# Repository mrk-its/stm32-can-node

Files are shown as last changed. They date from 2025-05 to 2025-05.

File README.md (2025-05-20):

# STM32 CAN Node

# Features

* modern STM32 MCU (U3/U5 series)
* integrated step-down converter (24V -> 3.3V)
* integrated CAN transceiver
* integrated 1-wire master controller (over i2c)
* 2.54 pin headers exposing 15 GPIOs
* separate SWD connector for flashing / debugging
* separate UART connector
* small form factor (40mm x 25mm)

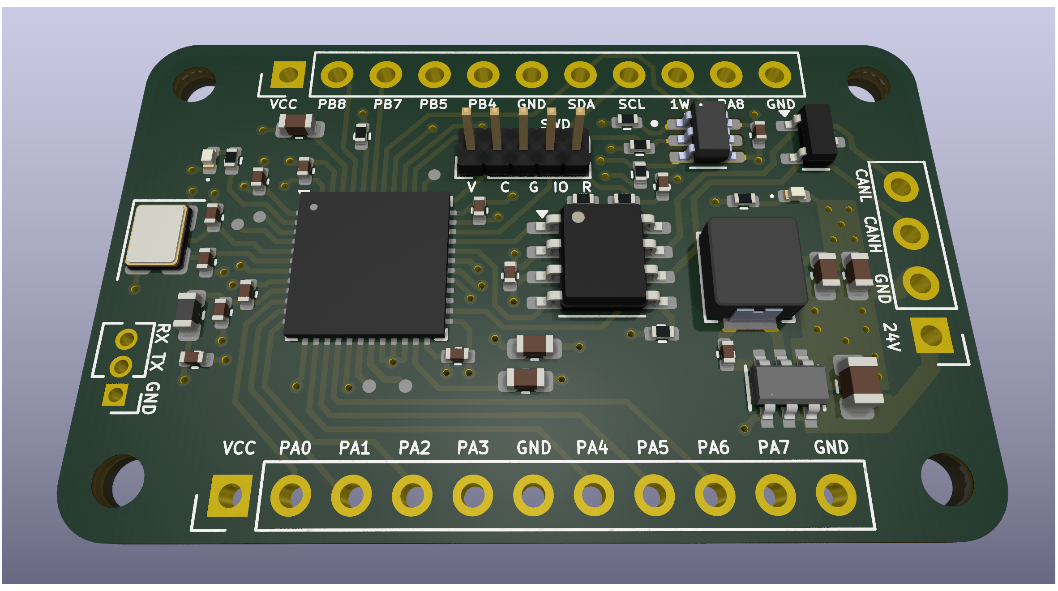
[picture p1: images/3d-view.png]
3d-view


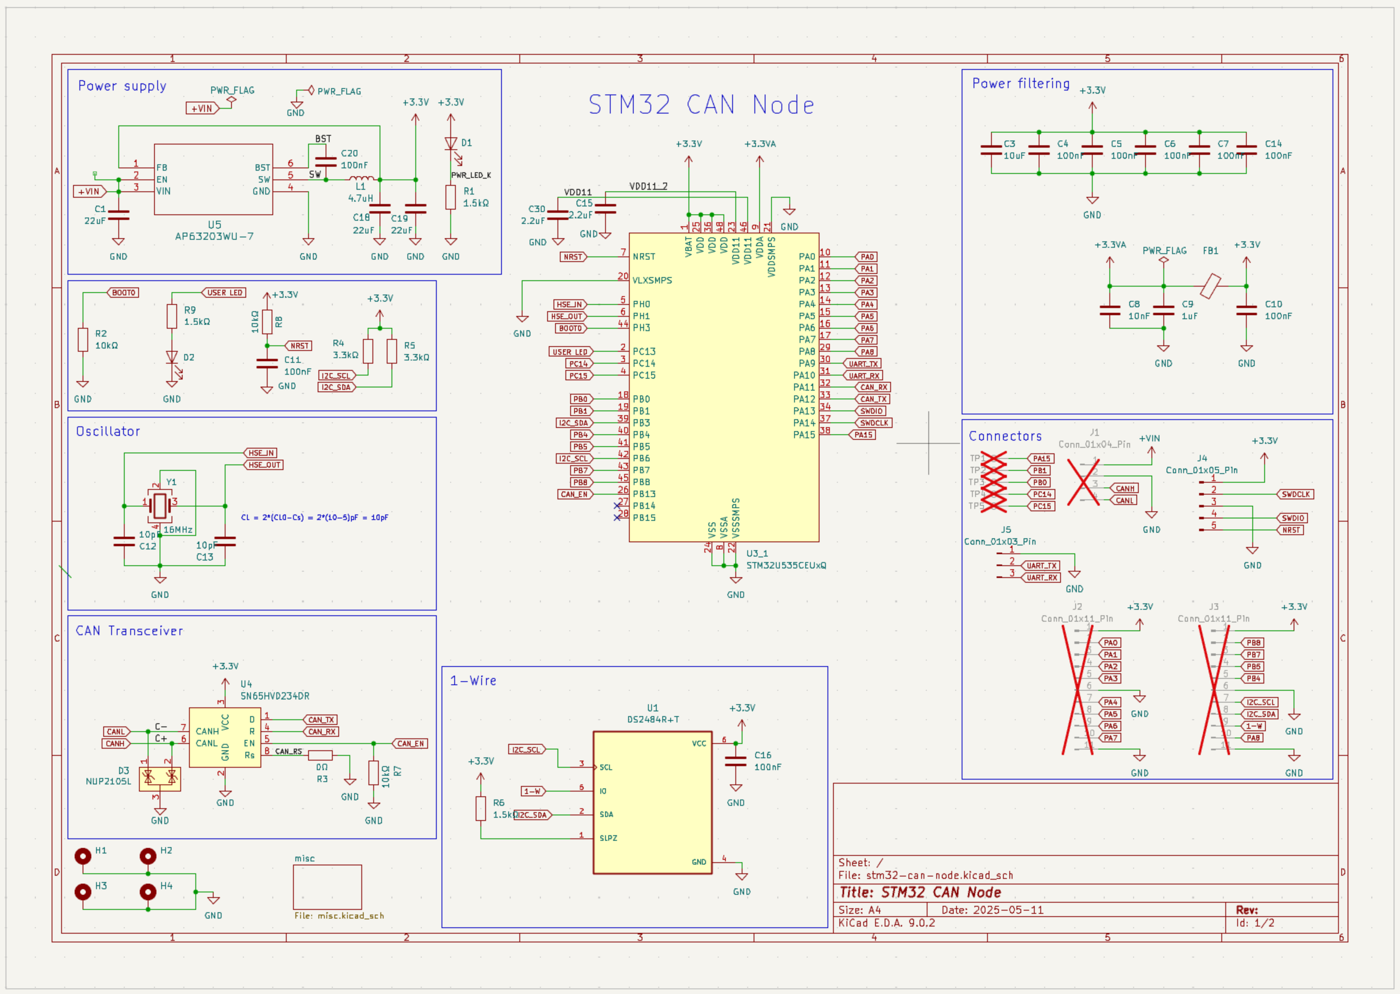
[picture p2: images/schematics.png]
schematics Schematics


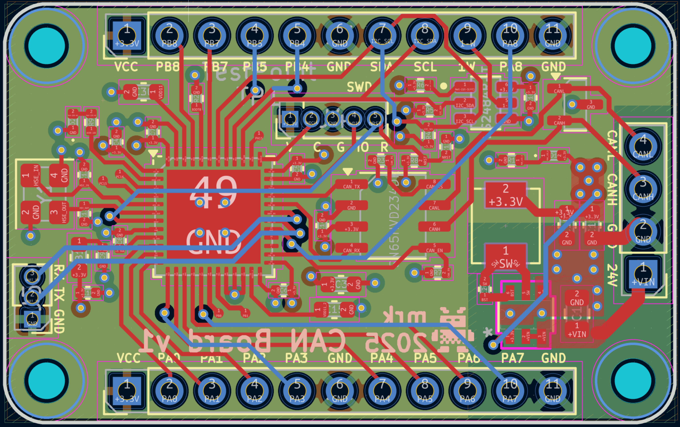
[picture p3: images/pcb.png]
schematics PCB


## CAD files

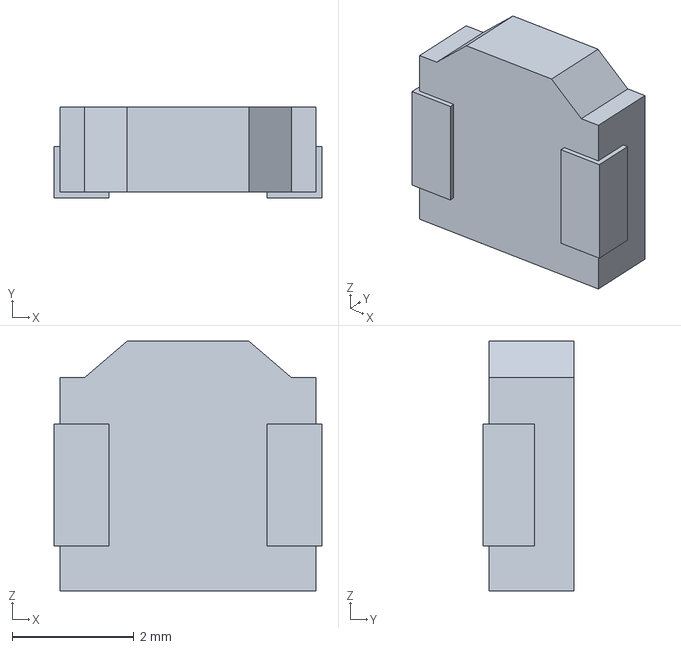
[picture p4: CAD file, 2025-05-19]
3dmodels/SPM4015T-4R7M-LR.step
4.40 x 1.50 x 4.10 mm

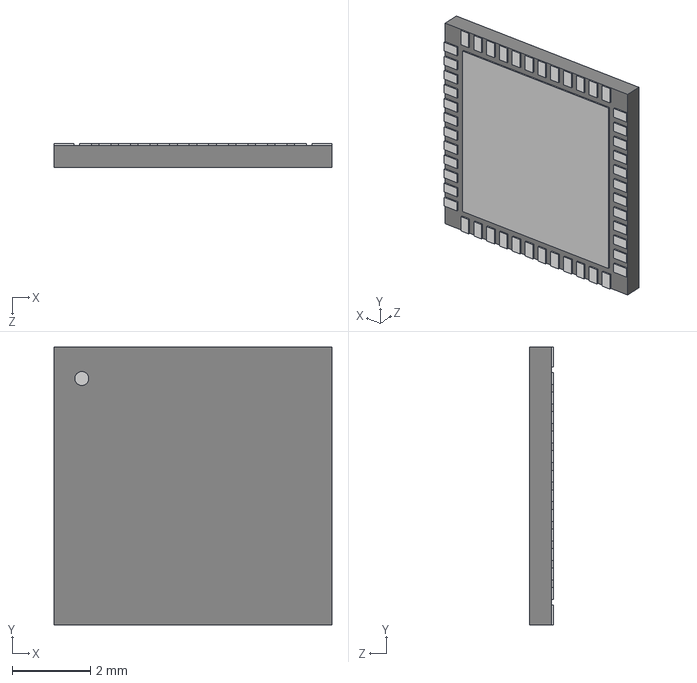
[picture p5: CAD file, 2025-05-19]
3dmodels/STM32U535CEU6Q.stp
7.11 x 7.11 x 0.612 mm

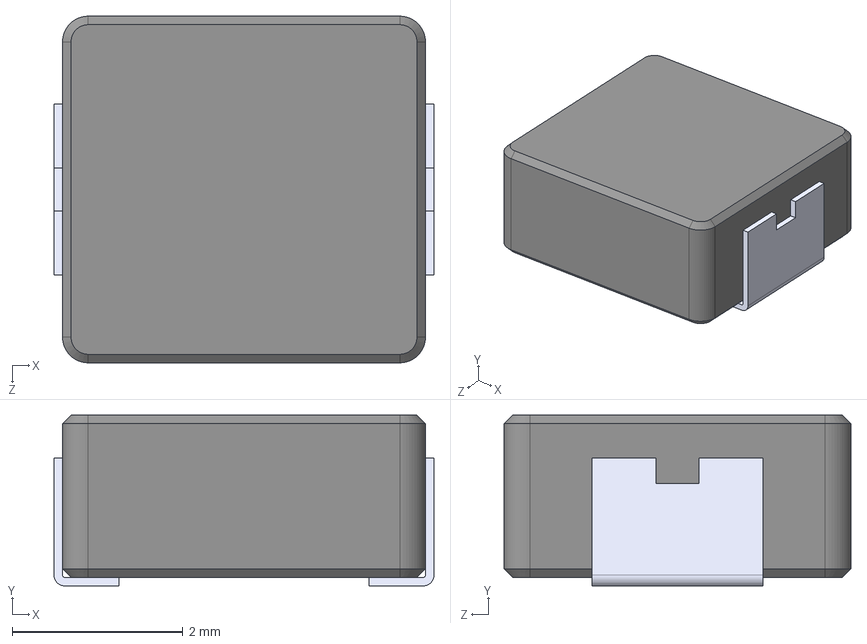
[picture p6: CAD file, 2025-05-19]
3dmodels/SRP4020TA-4R7M.step
4.45 x 2.00 x 4.06 mm

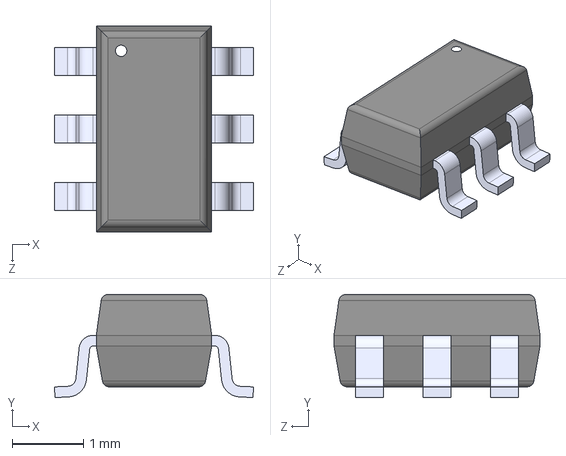
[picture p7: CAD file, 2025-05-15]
3dmodels/DS2484R+T.STEP
2.80 x 1.45 x 2.90 mm

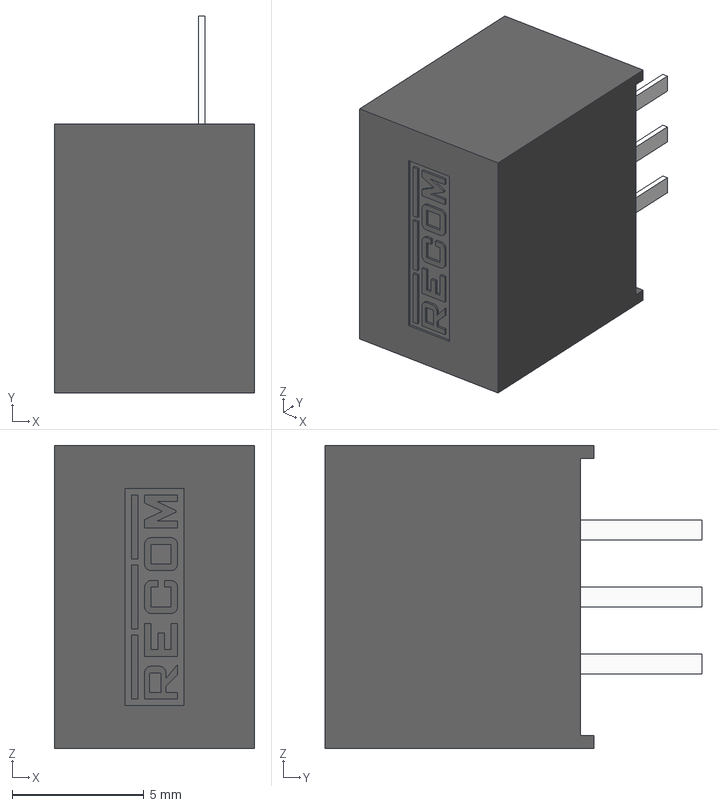
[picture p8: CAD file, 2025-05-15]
3dmodels/R-783.3-0.5.step
7.60 x 14.3 x 11.5 mm

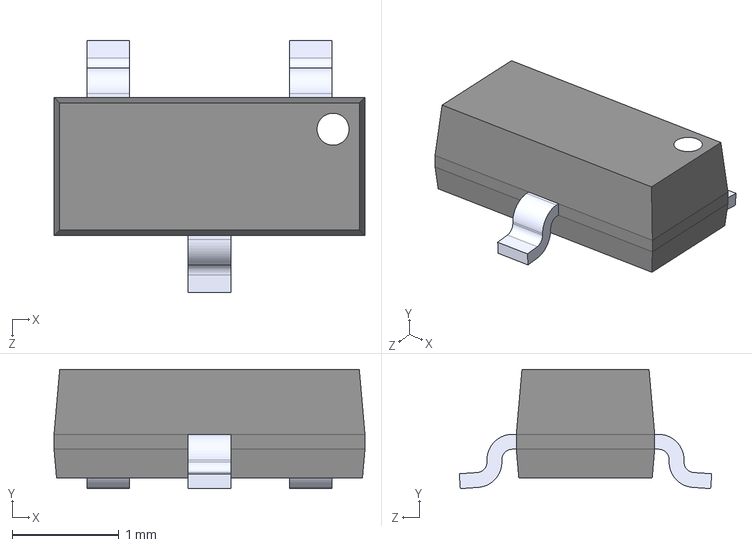
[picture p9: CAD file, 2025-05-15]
3dmodels/ESD2CAN24DBZRQ1.step
2.92 x 1.12 x 2.37 mm

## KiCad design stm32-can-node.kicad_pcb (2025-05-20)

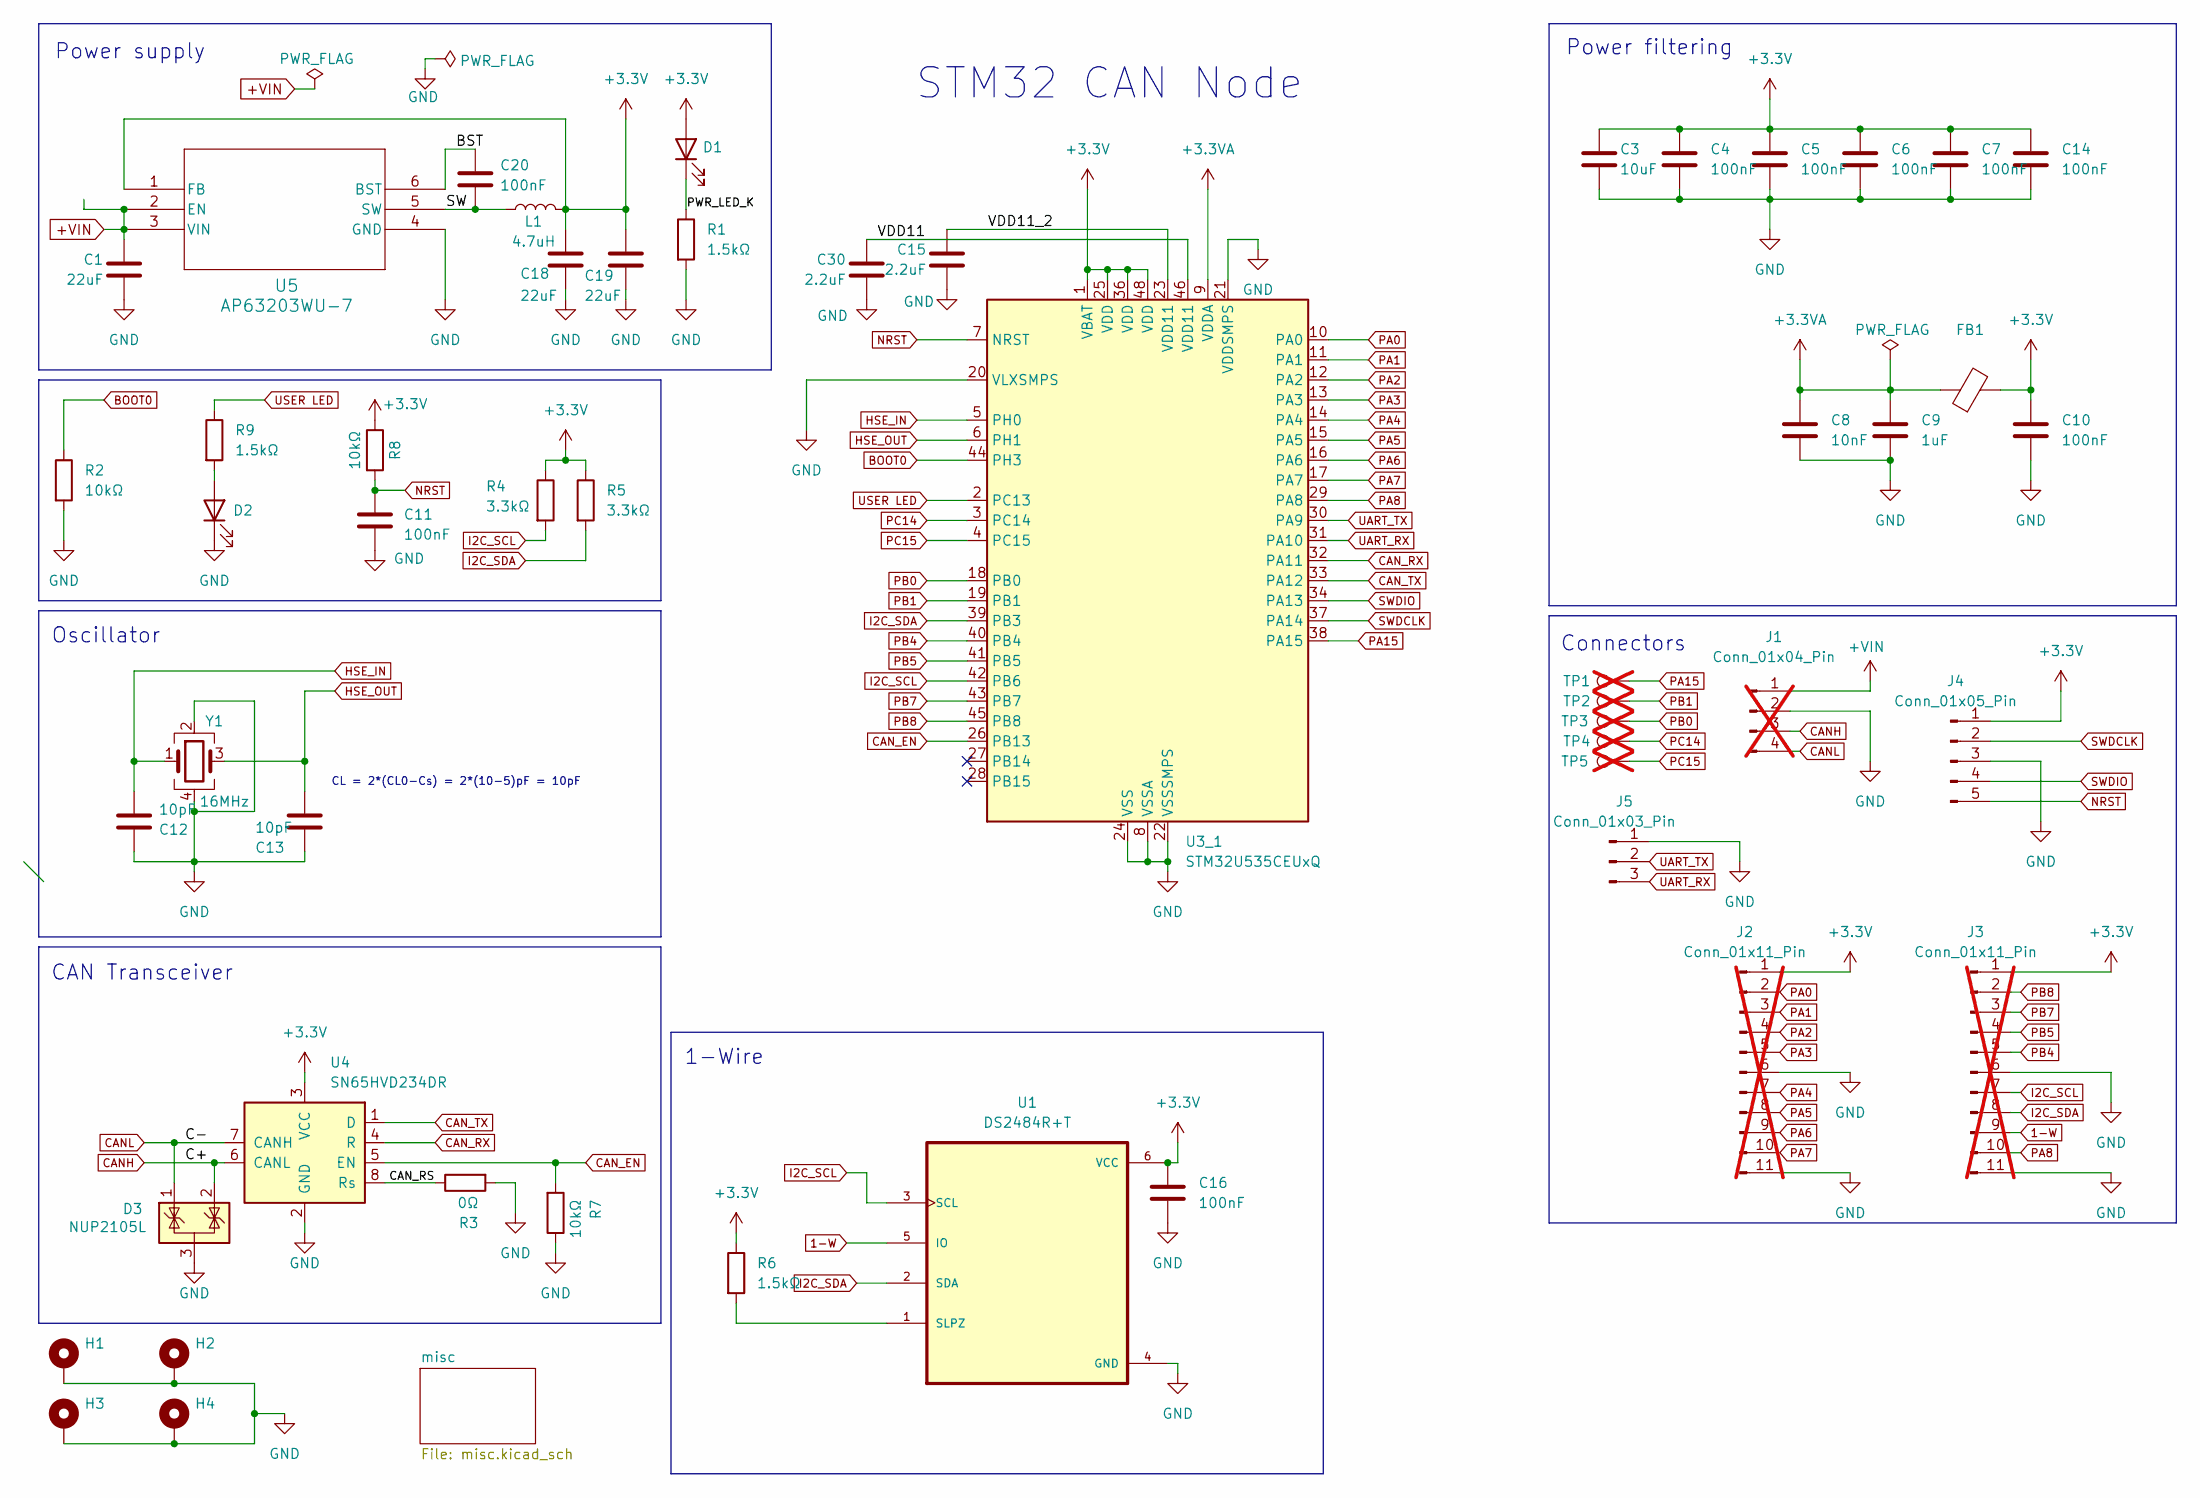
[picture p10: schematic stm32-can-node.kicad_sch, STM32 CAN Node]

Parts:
C1: 22uF; C_0805_2012Metric
C3: 10uF; C_0603_1608Metric
C4, C5, C6, C7, C10, C11, C14, C16, C20: 100nF; C_0402_1005Metric
C8: 10nF; C_0402_1005Metric
C9: 1uF; C_0402_1005Metric
C12, C13: 10pF; C_0402_1005Metric
C15, C30: 2.2uF; C_0603_1608Metric
C18, C19: 22uF; C_0603_1608Metric
D1: C397045; LED_0402_1005Metric
D2: C165977; LED_0402_1005Metric
D3: NUP2105L; SOT-23
FB1: FCM1608KF-601T05; L_0603_1608Metric; JLC C133937
H1, H2, H3, H4: MountingHole_Pad; MountingHole_2.2mm_M2_DIN965_Pad
J1: Conn_01x04_Pin; PinHeader_1x04_P2.54mm_Vertical; not fitted
J2, J3: Conn_01x11_Pin; PinHeader_1x11_P2.54mm_Vertical; not fitted
J4: Conn_01x05_Pin; PinHeader_1x05_P1.27mm_Vertical; JLC C2935945
J5: Conn_01x03_Pin; PinHeader_1x03_P1.27mm_Vertical; JLC C2935943
L1: 4.7uH; IND_SRP4020TA-4R7M
R1, R6, R9: 1.5kΩ; R_0402_1005Metric
R2, R7, R8: 10kΩ; R_0402_1005Metric
R3: 0Ω; R_0402_1005Metric
R4, R5: 3.3kΩ; R_0402_1005Metric
TP1, TP2, TP3, TP4, TP5: TestPoint; mini_test_point; not fitted
U1: DS2484R+T; DS2484; JLC C124886
U3_1: STM32U535CEUxQ; QFN-48-1EP_7x7mm_P0.5mm_EP5.6x5.6mm; JLC C22453481
U4: SN65HVD234DR; SOIC-8_3.9x4.9mm_P1.27mm; JLC C99818
U5: AP63203WU-7; AP63203WU-7_DIO; JLC C780769
Y1: 16MHz; Crystal_SMD_3225-4Pin_3.2x2.5mm; JLC C13738

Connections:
1-W: J3.9, U1.5 (IO)
+3.3V: C3.1, C4.1, C5.1, C6.1, C7.1, C10.1, C14.1, C16.1, C18.1, C19.1, D1.2 (A), FB1.2, J2.1, J3.1, J4.1, L1.2, R4.1, R5.1, R6.1, R8.1, U1.6 (VCC), U3_1.1 (VBAT), U3_1.25 (VDD), U3_1.36 (VDD), U3_1.48 (VDD), U4.3 (VCC), U5.1 (FB)
+3.3VA: C8.1, C9.1, FB1.1, U3_1.9 (VDDA)
+VIN: C1.1, J1.1, U5.2 (EN), U5.3 (VIN)
/BST: C20.1, U5.6 (BST)
/CAN_RS: R3.1, U4.8 (Rs)
/PWR_LED_K: D1.1 (K), R1.1
/SW: C20.2, L1.1, U5.5 (SW)
/VDD11: C30.1, U3_1.46 (VDD11)
/VDD11_2: C15.1, U3_1.23 (VDD11)
BOOT0: R2.1, U3_1.44 (PH3)
CANH: D3.2 (K), J1.3, U4.6 (CANL)
CANL: D3.1 (K), J1.4, U4.7 (CANH)
CAN_EN: R7.2, U3_1.26 (PB13), U4.5 (EN)
CAN_RX: U3_1.32 (PA11), U4.4 (R)
CAN_TX: U3_1.33 (PA12), U4.1 (D)
GND: C1.2, C3.2, C4.2, C5.2, C6.2, C7.2, C8.2, C9.2, C10.2, C11.1, C12.2, C13.2, C14.2, C15.2, C16.2, C18.2, C19.2, C30.2, D2.1 (K), D3.3 (A), H1.1, H2.1, H3.1, H4.1, J1.2, J2.6, J2.11, J3.6, J3.11, J4.3, J5.1, R1.2, R2.2, R3.2, R7.1, U1.4 (GND), U3_1.8 (VSSA), U3_1.20 (VLXSMPS), U3_1.21 (VDDSMPS), U3_1.22 (VSSSMPS), U3_1.24 (VSS), U3_1.35 (VSS), U3_1.47 (VSS), U3_1.49 (VSS), U4.2 (GND), U5.4 (GND), Y1.2, Y1.4
HSE_IN: C12.1, U3_1.5 (PH0), Y1.1
HSE_OUT: C13.1, U3_1.6 (PH1), Y1.3
I2C_SCL: J3.7, R4.2, U1.3 (SCL), U3_1.42 (PB6)
I2C_SDA: J3.8, R5.2, U1.2 (SDA), U3_1.39 (PB3)
NRST: C11.2, J4.5, R8.2, U3_1.7 (NRST)
unnamed: D2.2 (A), R9.2
unnamed: R6.2, U1.1 (SLPZ)
PA0: J2.2, U3_1.10 (PA0)
PA1: J2.3, U3_1.11 (PA1)
PA2: J2.4, U3_1.12 (PA2)
PA3: J2.5, U3_1.13 (PA3)
PA4: J2.7, U3_1.14 (PA4)
PA5: J2.8, U3_1.15 (PA5)
PA6: J2.9, U3_1.16 (PA6)
PA7: J2.10, U3_1.17 (PA7)
PA8: J3.10, U3_1.29 (PA8)
PA15: TP1.1, U3_1.38 (PA15)
PB0: TP3.1, U3_1.18 (PB0)
PB1: TP2.1, U3_1.19 (PB1)
PB4: J3.5, U3_1.40 (PB4)
PB5: J3.4, U3_1.41 (PB5)
PB7: J3.3, U3_1.43 (PB7)
PB8: J3.2, U3_1.45 (PB8)
PC14: TP4.1, U3_1.3 (PC14)
PC15: TP5.1, U3_1.4 (PC15)
SWDCLK: J4.2, U3_1.37 (PA14)
SWDIO: J4.4, U3_1.34 (PA13)
UART_RX: J5.3, U3_1.31 (PA10)
UART_TX: J5.2, U3_1.30 (PA9)
USER LED: R9.1, U3_1.2 (PC13)

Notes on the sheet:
CL = 2*(CL0-Cs) = 2*(10-5)pF = 10pF
STM32 CAN Node
Oscillator
Power filtering
1-Wire
Connectors
Power supply
CAN Transceiver

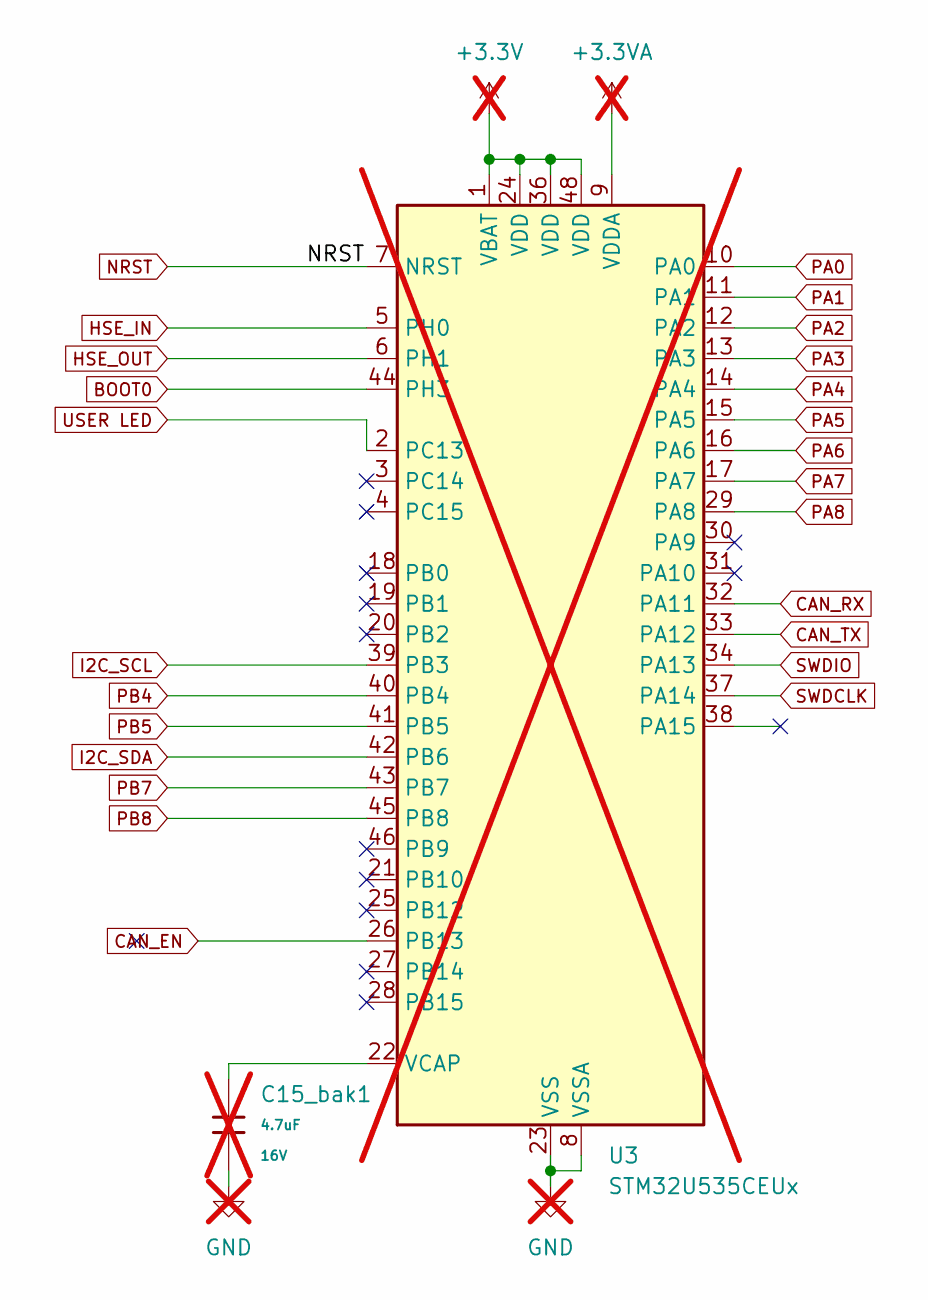
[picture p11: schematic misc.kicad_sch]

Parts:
C15_bak1: 4.7uF; C_0603_1608Metric; Voltage Rated 16V; Tolerance ±10%; Part CL10A475KO8NNNC; LCSC C19666; not fitted
U3: STM32U535CEUx; QFN-48-1EP_7x7mm_P0.5mm_EP5.6x5.6mm; not fitted

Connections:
unnamed: C15_bak1.1, U3.22 (VCAP)
unnamed: C15_bak1.2, U3.8 (VSSA), U3.23 (VSS), U3.35 (VSS), U3.47 (VSS), U3.49 (VSS)
unnamed: U3.1 (VBAT), U3.24 (VDD), U3.36 (VDD), U3.48 (VDD)

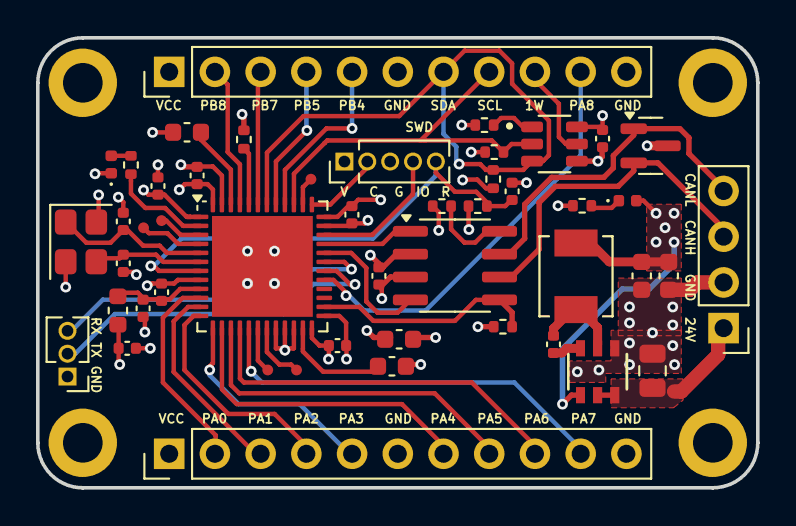
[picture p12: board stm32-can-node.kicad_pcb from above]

Board: 4 copper layers, 40.0 x 25.0 mm, 52 parts (0 on the bottom side), 47 nets.

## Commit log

2025-05-16 better pcb layout
    [stm32-can-node.kicad_pcb, stm32-can-node.kicad_sch]
2025-05-16 change to 11-pin connectors
    [stm32-can-node.kicad_pcb, stm32-can-node.kicad_sch]
2025-05-17 add step-down converter, update part values
    [stm32-can-node.kicad_pcb, stm32-can-node.kicad_sch]
2025-05-17 remove vias under mcu
    [stm32-can-node.kicad_pcb]
2025-05-19 support for UFQFPN48_SMPS
    [stm32-can-node.kicad_pcb, stm32-can-node.kicad_sch]
2025-05-19 add 3d models
    [SPM4015T-4R7M-LR.step, SRP4020TA-4R7M.step, STM32U535CEU6Q.stp]
2025-05-19 update images
    [stm32-can-node.kicad_pcb, stm32-can-node.kicad_sch]
2025-05-20 added uart header
    [stm32-can-node.kicad_pcb, stm32-can-node.kicad_sch]
2025-05-20 final changes before production
    [stm32-can-node.kicad_pcb, stm32-can-node.kicad_sch]
2025-05-21 add missing file
    [misc.kicad_sch]
